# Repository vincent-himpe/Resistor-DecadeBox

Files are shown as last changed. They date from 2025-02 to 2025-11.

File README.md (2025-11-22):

# Resistor-DecadeBox
Resistor Decade Box 0 - 999999 Ohm

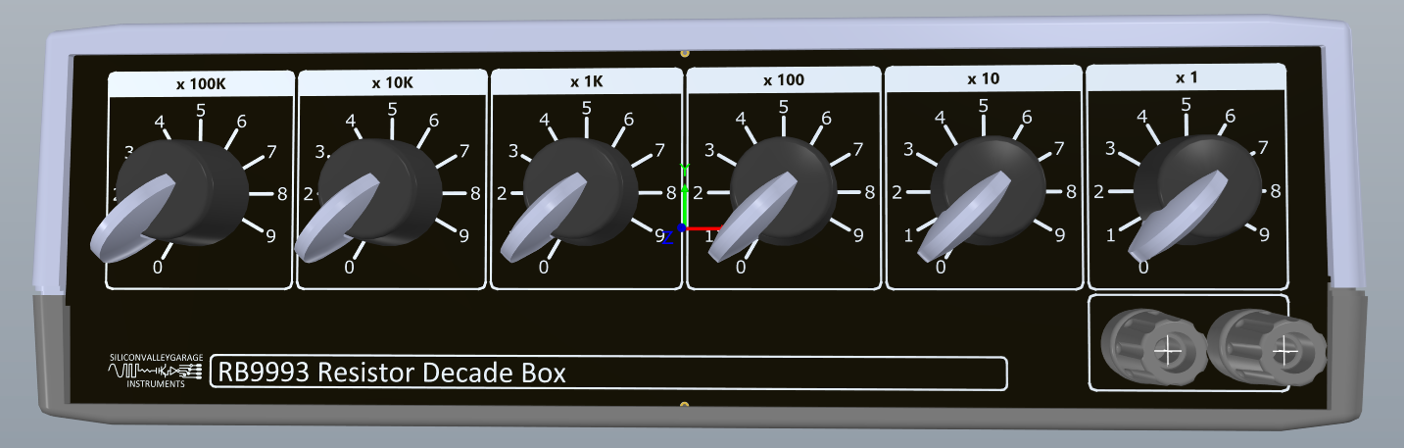
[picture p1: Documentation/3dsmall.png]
Resistor Decade Box


A Decade Resistor box using 2 Watt 1% resistors.( 3watt for the 1 ohm resistors )
The good quality boxes out there are very expensive. The "ebay" boxes invariably use sloppy switches and 0603 resistors that go -poof- if you just look at them.

So i decided to roll my own.

## Features:

- Hammond R2095 Enclosure
- Alpha Japan switches
- Yageo FMP300/FMP200  resistors (3 watt, 2 Watt 1% Metalfilm, flameproof)
- Cliff Electronics Binding Posts with 4mm Bana Jack
- OKW Topknob
- Double Sided PCB
- Front panel as PCB

## Layout

The Board is a 2 layer PCB that can easily be produced by the likes of JLCPCB or PCBway.  A full production pack (Gerber / NCdrill, BOM , Pick and place ) is available. You can send the ZIP files directly to JLCPCB.

## Assembly

The Bom is included in the PDF

## Source Files

All source files are available in Altium Format. That's what i know, have and use. Other CAD programs most likely can import those. So you can modify it if you want.

## License

The project is PUBLIC DOMAIN. Do as you please. No warranties, As-Is
Creative Commons Zero.

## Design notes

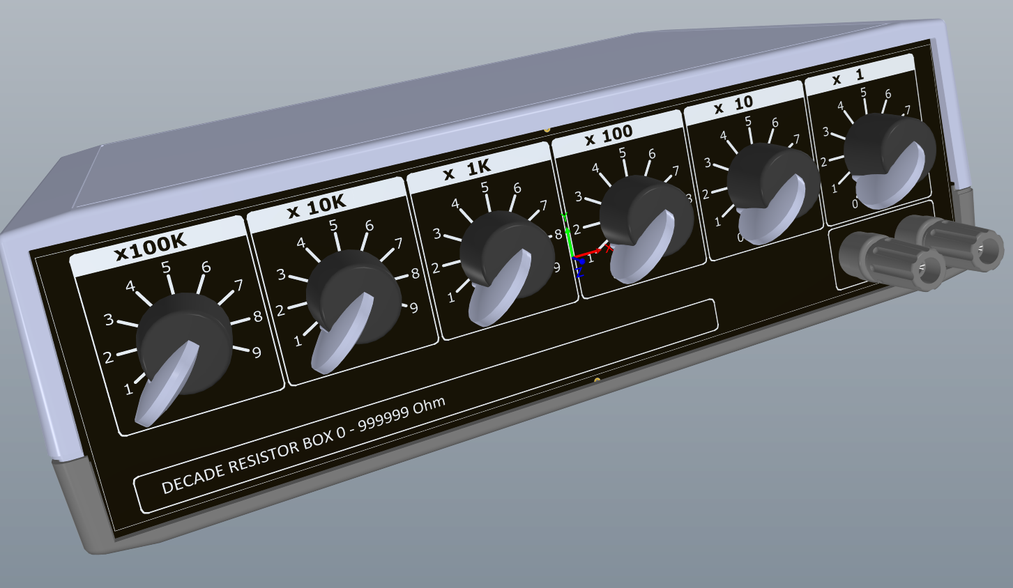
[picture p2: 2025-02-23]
Documentation/3d.png

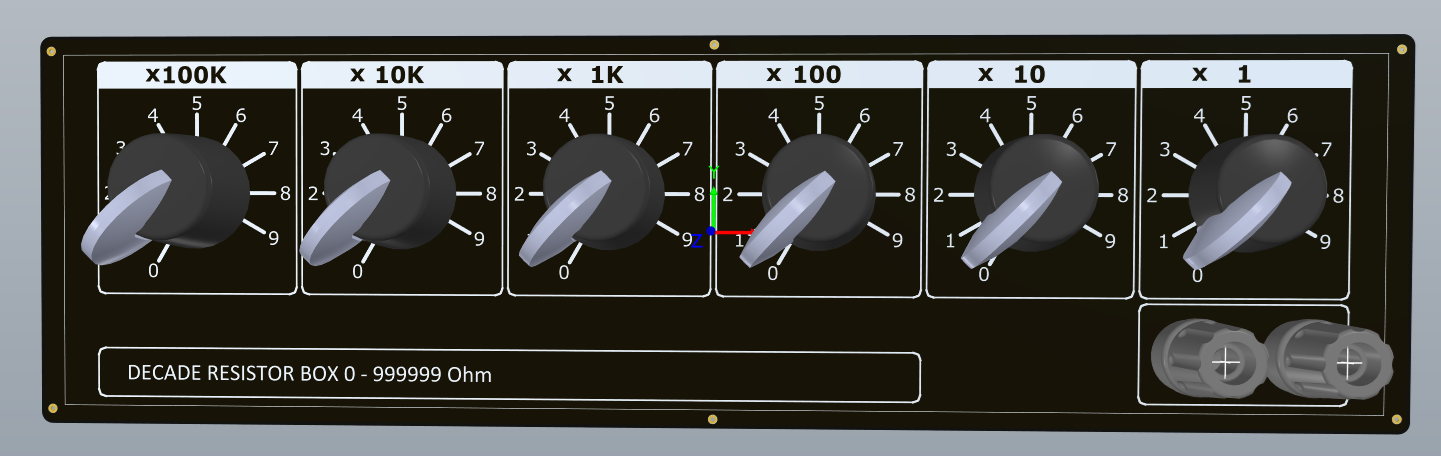
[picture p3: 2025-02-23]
Documentation/front.png

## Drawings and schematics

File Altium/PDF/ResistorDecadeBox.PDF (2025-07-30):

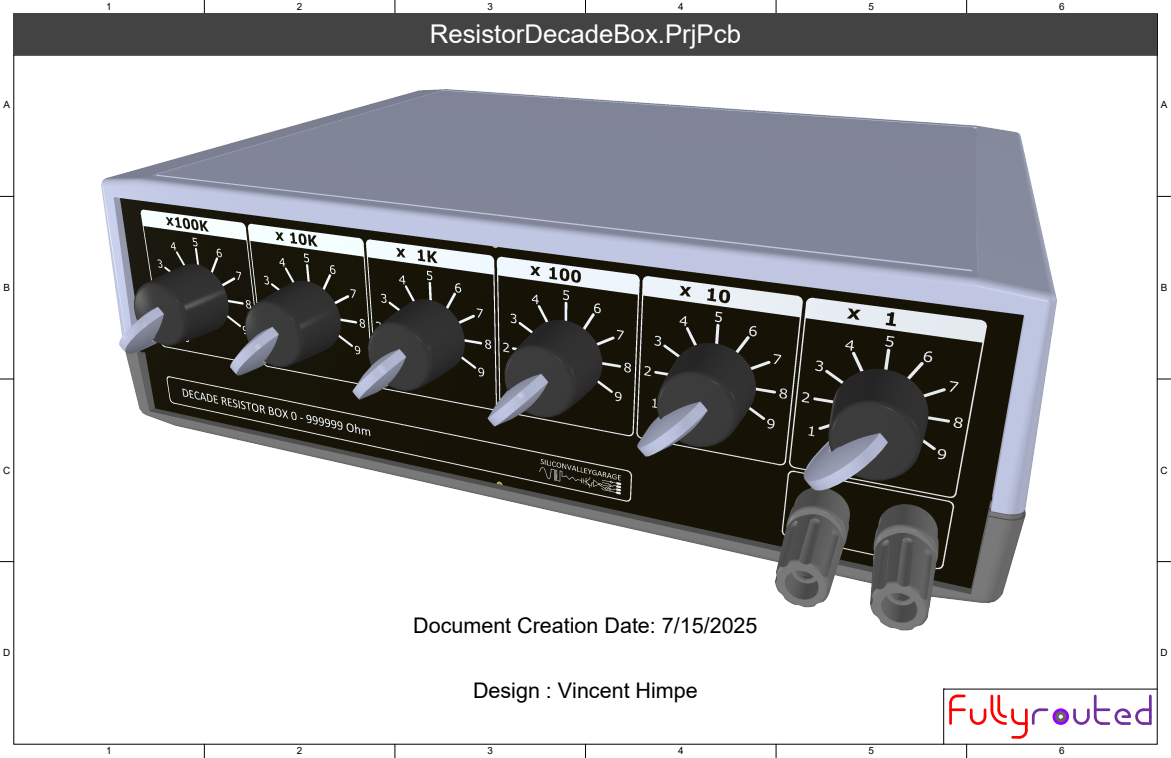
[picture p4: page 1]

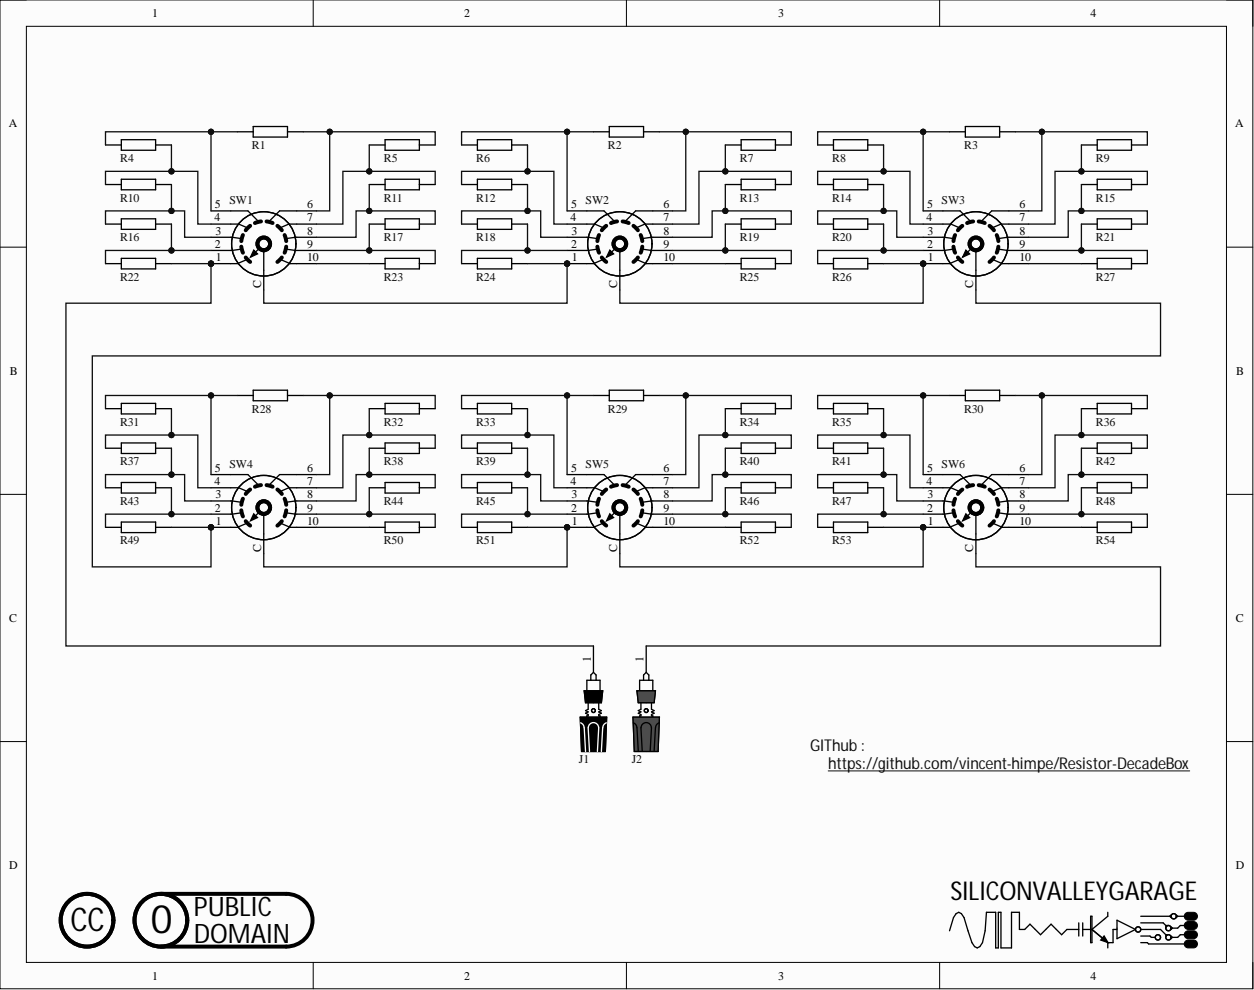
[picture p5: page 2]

GIThub :
https://github.com/vincent-himpe/Resistor-DecadeBox

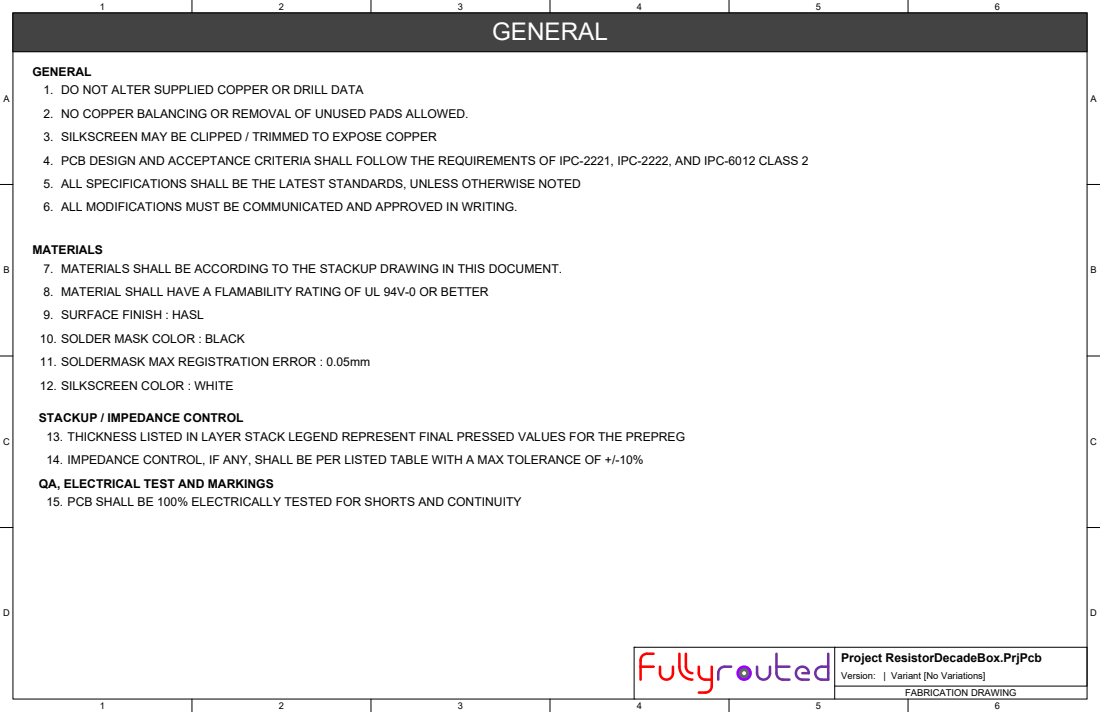
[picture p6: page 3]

GENERAL
1. DO NOT ALTER SUPPLIED COPPER OR DRILL DATA
2. NO COPPER BALANCING OR REMOVAL OF UNUSED PADS ALLOWED.
3. SILKSCREEN MAY BE CLIPPED / TRIMMED TO EXPOSE COPPER
4. PCB DESIGN AND ACCEPTANCE CRITERIA SHALL FOLLOW THE REQUIREMENTS OF IPC-2221, IPC-2222, AND IPC-6012 CLASS 2
5. ALL SPECIFICATIONS SHALL BE THE LATEST STANDARDS, UNLESS OTHERWISE NOTED
6. ALL MODIFICATIONS MUST BE COMMUNICATED AND APPROVED IN WRITING.

MATERIALS
7. MATERIALS SHALL BE ACCORDING TO THE STACKUP DRAWING IN THIS DOCUMENT.
8. MATERIAL SHALL HAVE A FLAMABILITY RATING OF UL 94V-0 OR BETTER
9. SURFACE FINISH : HASL
10. SOLDER MASK COLOR : BLACK
11. SOLDERMASK MAX REGISTRATION ERROR : 0.05mm
12. SILKSCREEN COLOR : WHITE

STACKUP / IMPEDANCE CONTROL
13. THICKNESS LISTED IN LAYER STACK LEGEND REPRESENT FINAL PRESSED VALUES FOR THE PREPREG
14. IMPEDANCE CONTROL, IF ANY, SHALL BE PER LISTED TABLE WITH A MAX TOLERANCE OF +/-10%
QA, ELECTRICAL TEST AND MARKINGS
15. PCB SHALL BE 100% ELECTRICALLY TESTED FOR SHORTS AND CONTINUITY

Project ResistorDecadeBox.PrjPcb
Version: | Variant [No Variations]

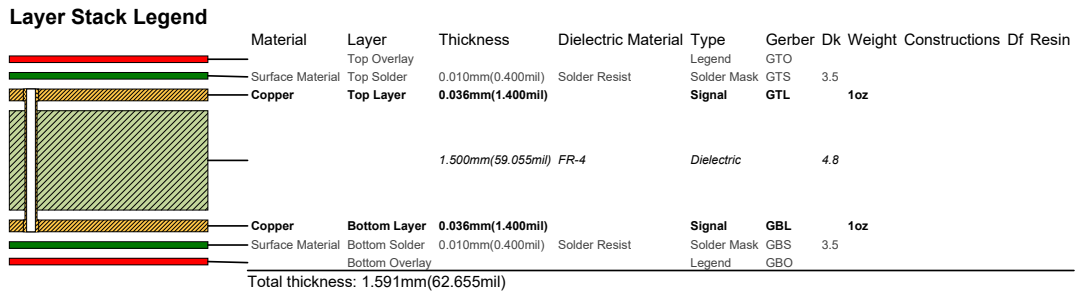
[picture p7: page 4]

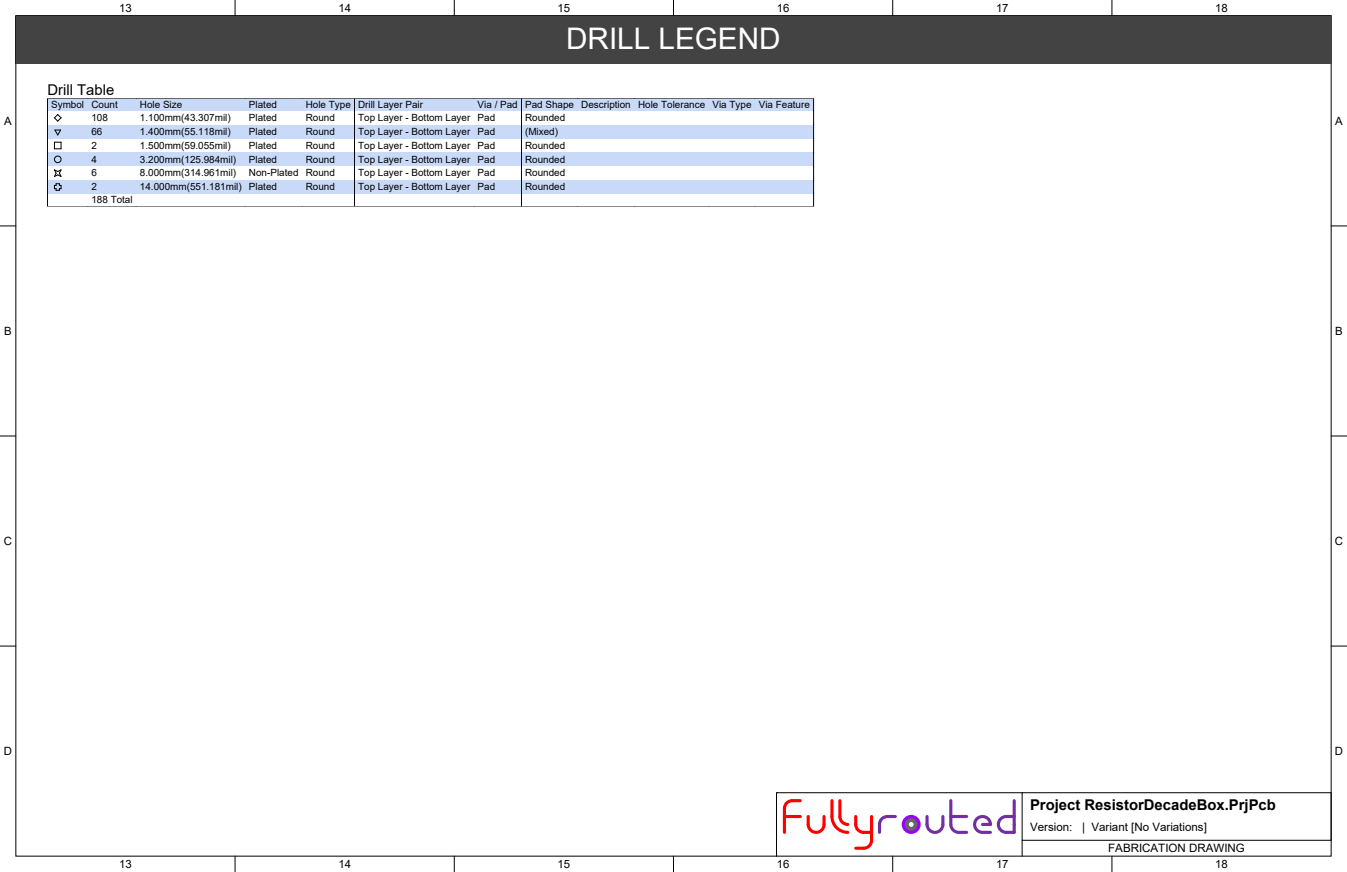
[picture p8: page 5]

Symbol | Count | Hole Size | Plated | Hole Type | Drill Layer Pair | Via / Pad | Pad Shape | Description | Hole Tolerance | Via Type | Via Feature

108 | 1.100mm(43.307mil) | Plated | Round | Top Layer - Bottom Layer | Pad | Rounded
66 | 1.400mm(55.118mil) | Plated | Round | Top Layer - Bottom Layer | Pad | (Mixed)
2 | 1.500mm(59.055mil) | Plated | Round | Top Layer - Bottom Layer | Pad | Rounded
4 | 3.200mm(125.984mil) | Plated | Round | Top Layer - Bottom Layer | Pad | Rounded
6 | 8.000mm(314.961mil) | Non-Plated | Round | Top Layer - Bottom Layer | Pad | Rounded
2 | 14.000mm(551.181mil) | Plated | Round | Top Layer - Bottom Layer | Pad | Rounded
188 Total

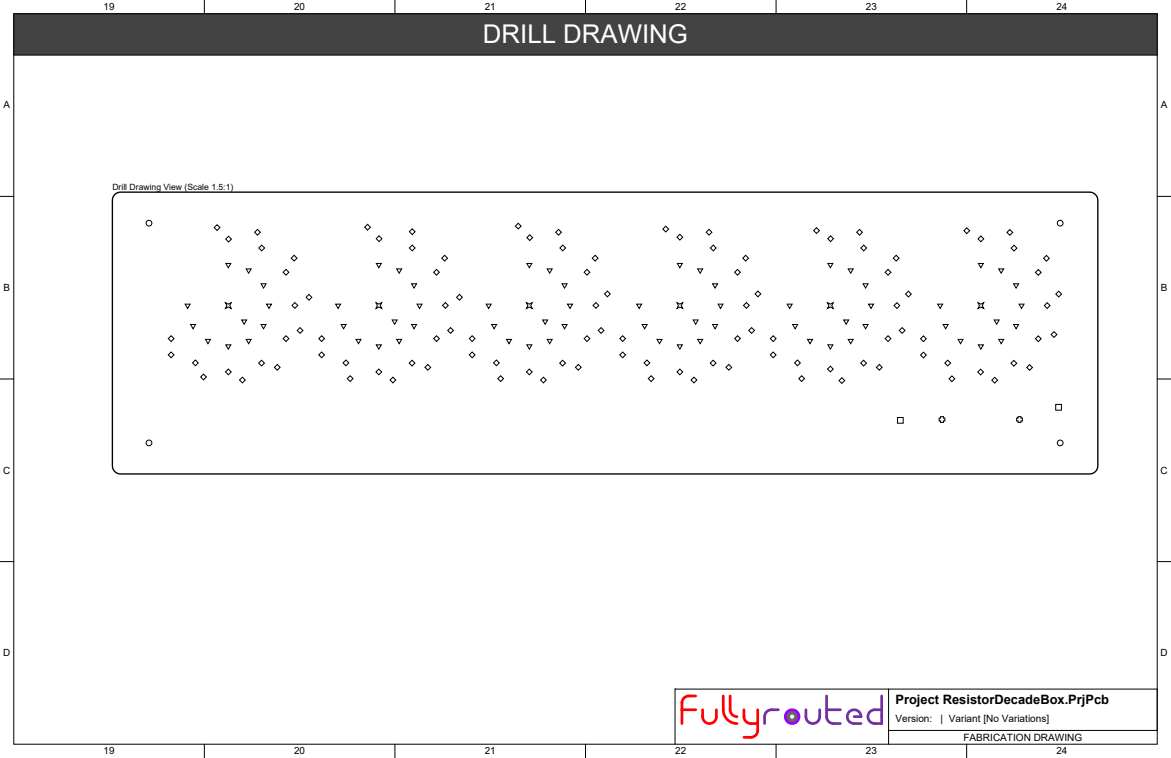
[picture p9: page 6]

Drill Drawing View (Scale 1.5:1)

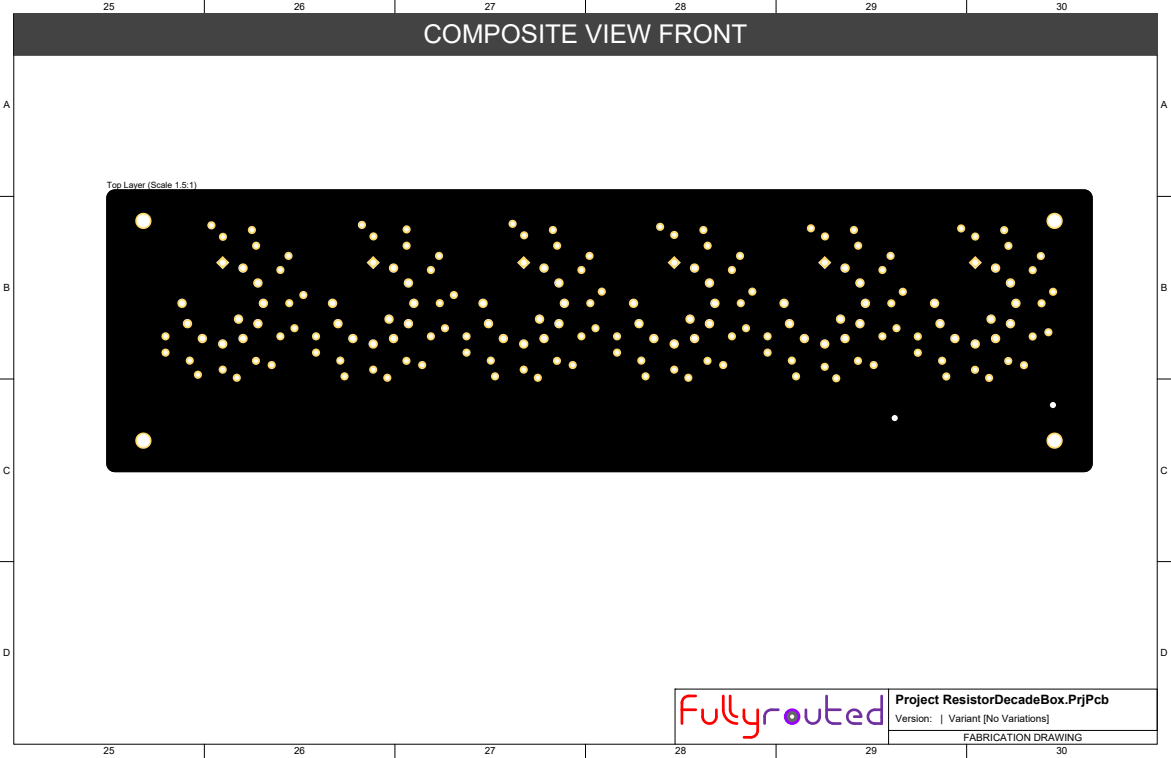
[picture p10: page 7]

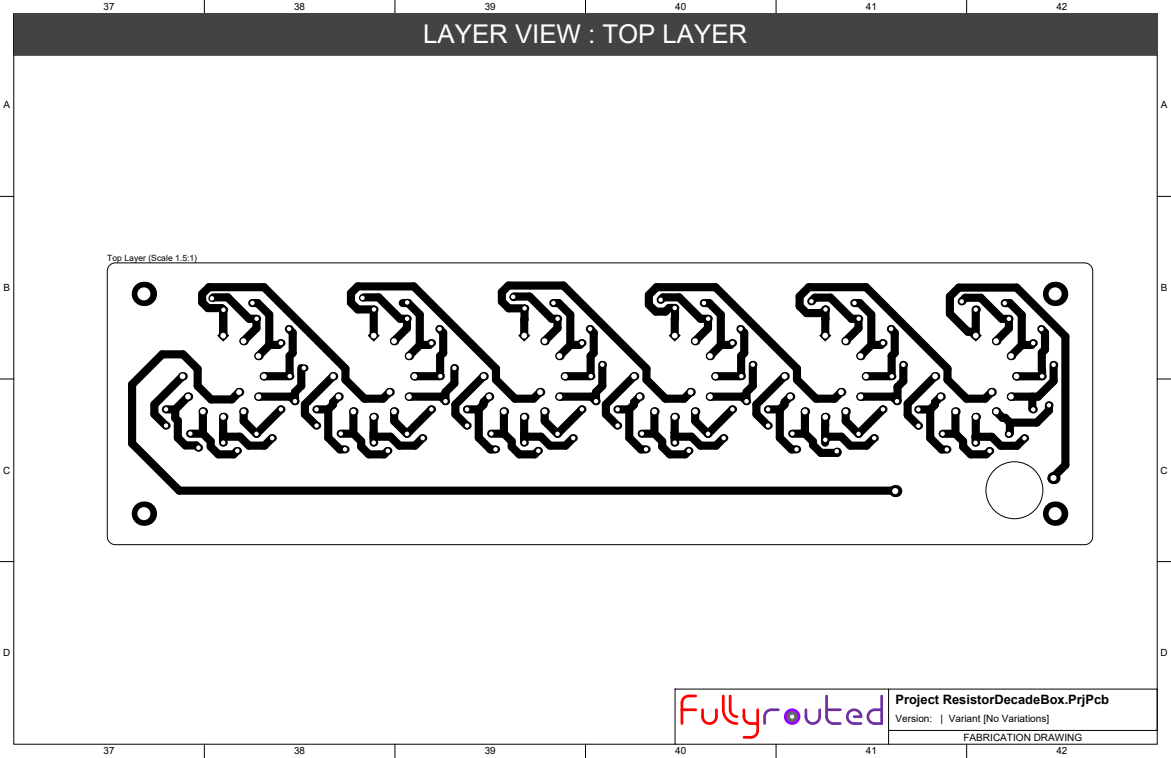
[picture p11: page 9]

LAYER VIEW : TOP LAYER

LAYER VIEW : BOTTOM LAYER

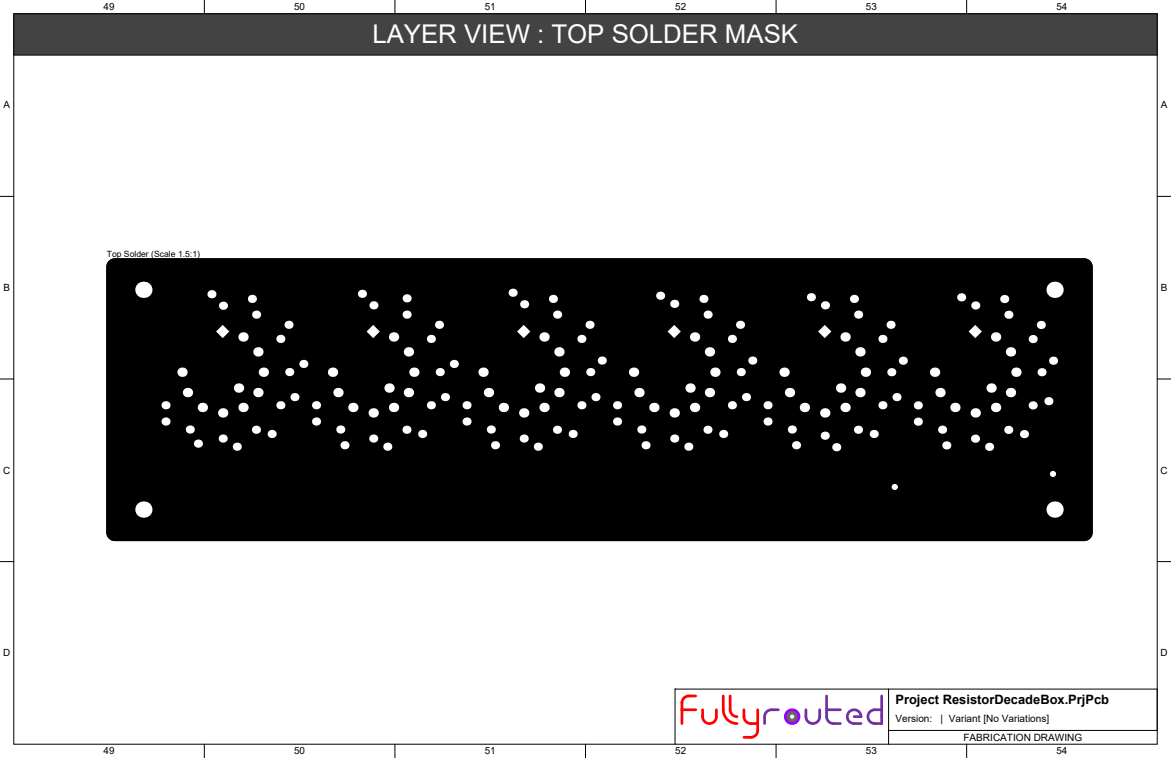
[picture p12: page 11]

LAYER VIEW : TOP SOLDER MASK

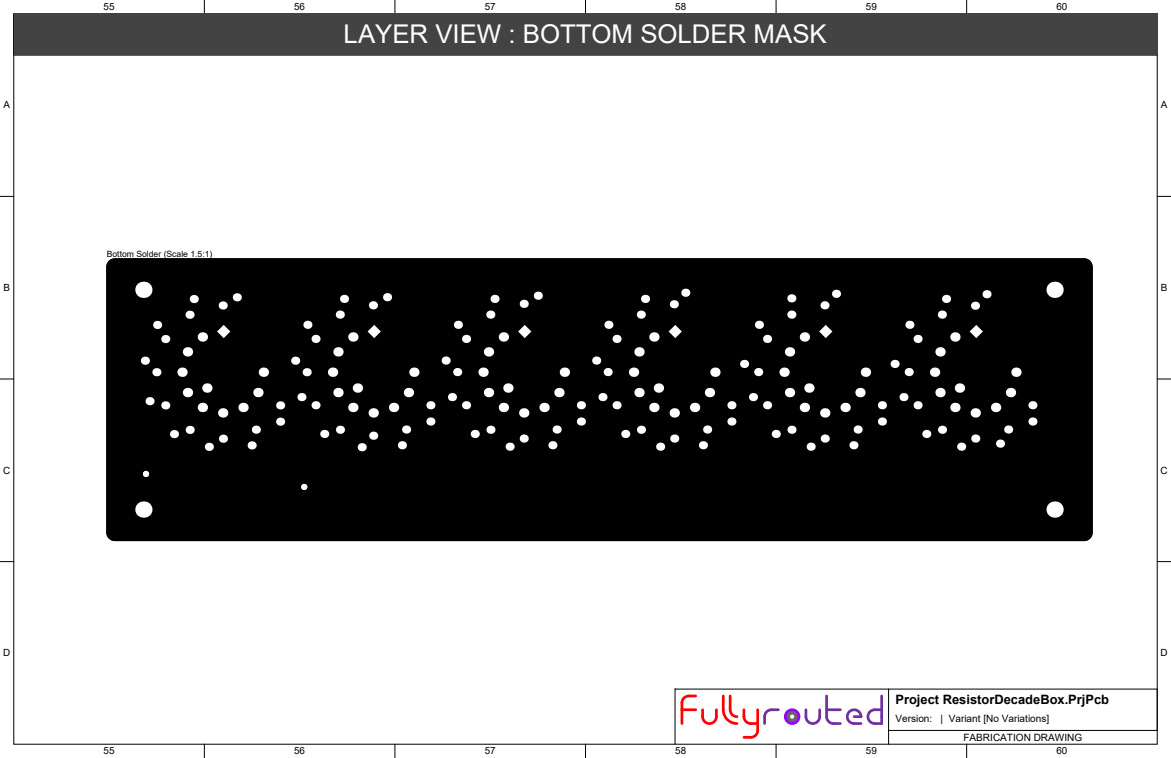
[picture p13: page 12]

LAYER VIEW : BOTTOM SOLDER MASK

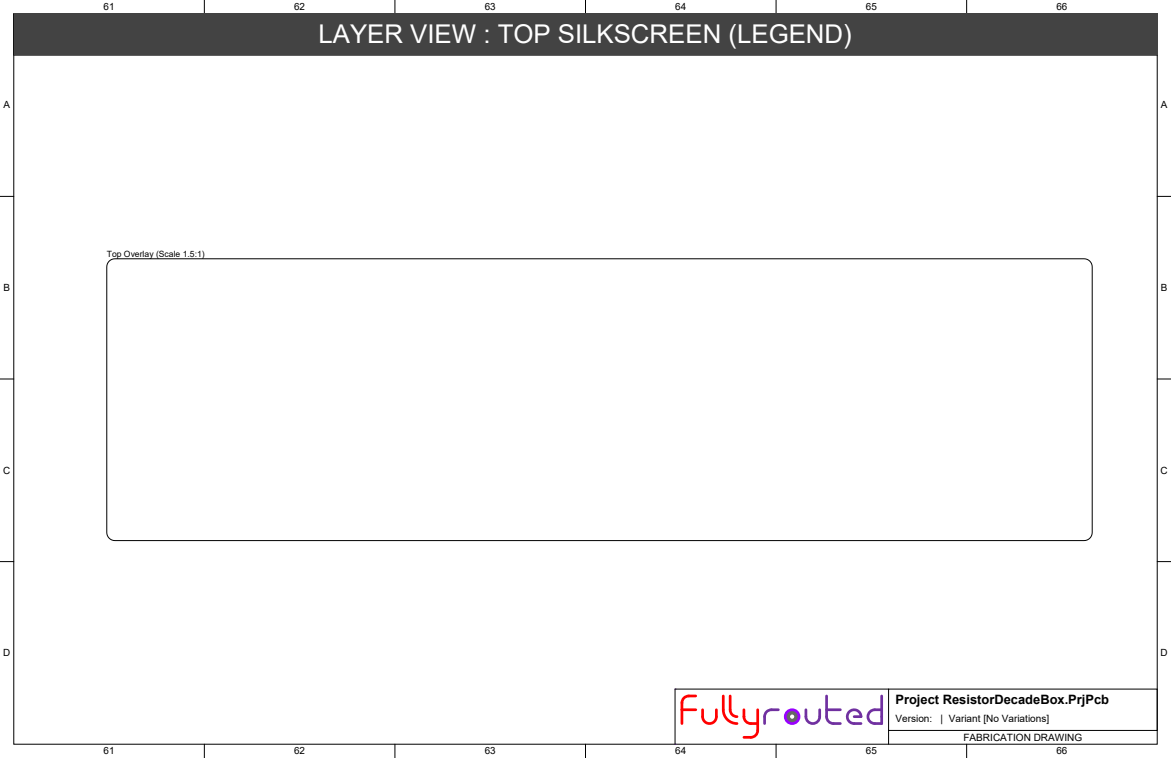
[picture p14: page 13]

LAYER VIEW : TOP SILKSCREEN (LEGEND)

LAYER VIEW : BOTTOM SILKSCREEN (LEGEND)

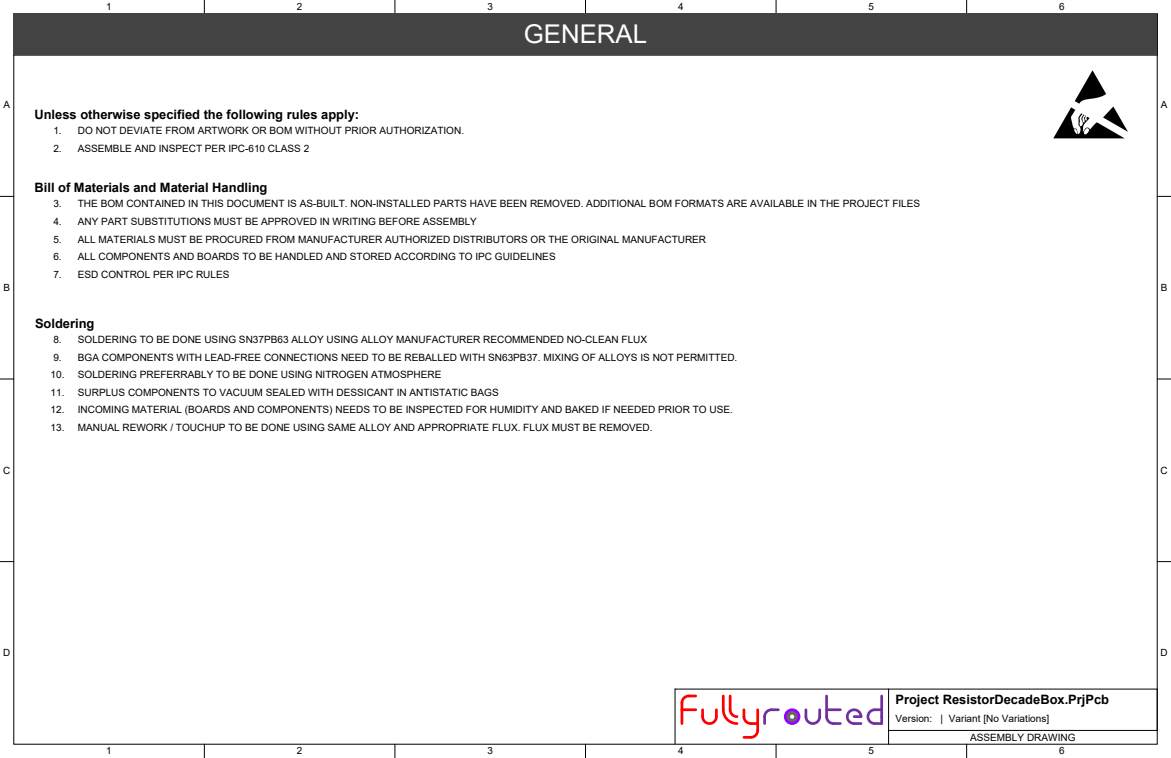
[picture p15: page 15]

Unless otherwise specified the following rules apply:
1. DO NOT DEVIATE FROM ARTWORK OR BOM WITHOUT PRIOR AUTHORIZATION.
2. ASSEMBLE AND INSPECT PER IPC-610 CLASS 2

Bill of Materials and Material Handling
3. THE BOM CONTAINED IN THIS DOCUMENT IS AS-BUILT. NON-INSTALLED PARTS HAVE BEEN REMOVED. ADDITIONAL BOM FORMATS ARE AVAILABLE IN THE PROJECT FILES
4. ANY PART SUBSTITUTIONS MUST BE APPROVED IN WRITING BEFORE ASSEMBLY
5. ALL MATERIALS MUST BE PROCURED FROM MANUFACTURER AUTHORIZED DISTRIBUTORS OR THE ORIGINAL MANUFACTURER
6. ALL COMPONENTS AND BOARDS TO BE HANDLED AND STORED ACCORDING TO IPC GUIDELINES
7. ESD CONTROL PER IPC RULES

Soldering
8. SOLDERING TO BE DONE USING SN37PB63 ALLOY USING ALLOY MANUFACTURER RECOMMENDED NO-CLEAN FLUX
9. BGA COMPONENTS WITH LEAD-FREE CONNECTIONS NEED TO BE REBALLED WITH SN63PB37. MIXING OF ALLOYS IS NOT PERMITTED.
10. SOLDERING PREFERRABLY TO BE DONE USING NITROGEN ATMOSPHERE
11. SURPLUS COMPONENTS TO VACUUM SEALED WITH DESSICANT IN ANTISTATIC BAGS
12. INCOMING MATERIAL (BOARDS AND COMPONENTS) NEEDS TO BE INSPECTED FOR HUMIDITY AND BAKED IF NEEDED PRIOR TO USE.
13. MANUAL REWORK / TOUCHUP TO BE DONE USING SAME ALLOY AND APPROPRIATE FLUX. FLUX MUST BE REMOVED.


View from Front side (Scale 1:1)

View from Top side (Scale 1:1)

View from Bottom side (Scale 1:1)

View from Back side (Scale 1:1)


View from Bottom side (Scale 1:1)

View from Top side (Scale 1:1)


Quantity | Designator | Description | MOUSER
1 | J1
1 | J2
1 | LOGO3
54 | R1, R2, R3, R4, R5, R6, R7, R8, R9, R10, R11, R12, R13, R14, R15, R16, R17, R18, R19, R20, R21, R22, R23, R24, R25, R26, R27, R28, R29, R30, R31, R32, R33, R34, R35, R36, R37, R38, R39, R40, R41, R42, R43, R44, R45, R46, R47, R48, R49, R50, R51, R52, R53, R54


View from Top side (Scale 1:1)

View from Bottom side (Scale 1:1)

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
